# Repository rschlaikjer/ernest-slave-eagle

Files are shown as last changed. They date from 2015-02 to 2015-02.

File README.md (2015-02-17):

# Ernest Slave Node Schematics
Eagle files for data collection nodes

[Master Project Repo](https://github.com/rschlaikjer/Ernest)

## What is this
Ernest is the next step of the [ArNest](https://github.com/rschlaikjer/ArNest),
and takes it from a single-location thermostat to a many node system consisting
of a base station and one or more smaller nodes that collect and report
atmospheric data to the base. This way the system can monitor multiple rooms, as
well as the outside conditions.

These EAGLE files show the schematic for hooking up the slave nodes, as well as
a board layout for printing your own slave boards.

For the code to run on the slave nodes,
[see here](https://github.com/rschlaikjer/ernest-slave-code).

## Parts list
(All prices per unit and approximate)

- ($2.00) Atmega 328P (with arduino-style bootloader)
- ($3.19) USB FTDI programmer
- ($1.50) BMP180 breakout board
- ($13.75) (Optional) HIH-6130 humidity sensor
- ($0.98) nrf24L01 wireless transciever
- ($0.39) LM1117 3.3V regulator
- ($0.07) 16 MHz crystal oscillator
- ($0.03) 22pF capacitors
- ($0.08) Momentary reset switch
- ($0.32) 4-pin DIP switch
- ($0.01) 320 Ohm resistors
- ($0.03) LEDs
- ($0.30) 2.5mm barrel jack (for power)

**Total BOM: Approx. $5.86 per board** + 13.75 for humidity, as well as the cost
of PCB manufacture.

## Pretty Pictures

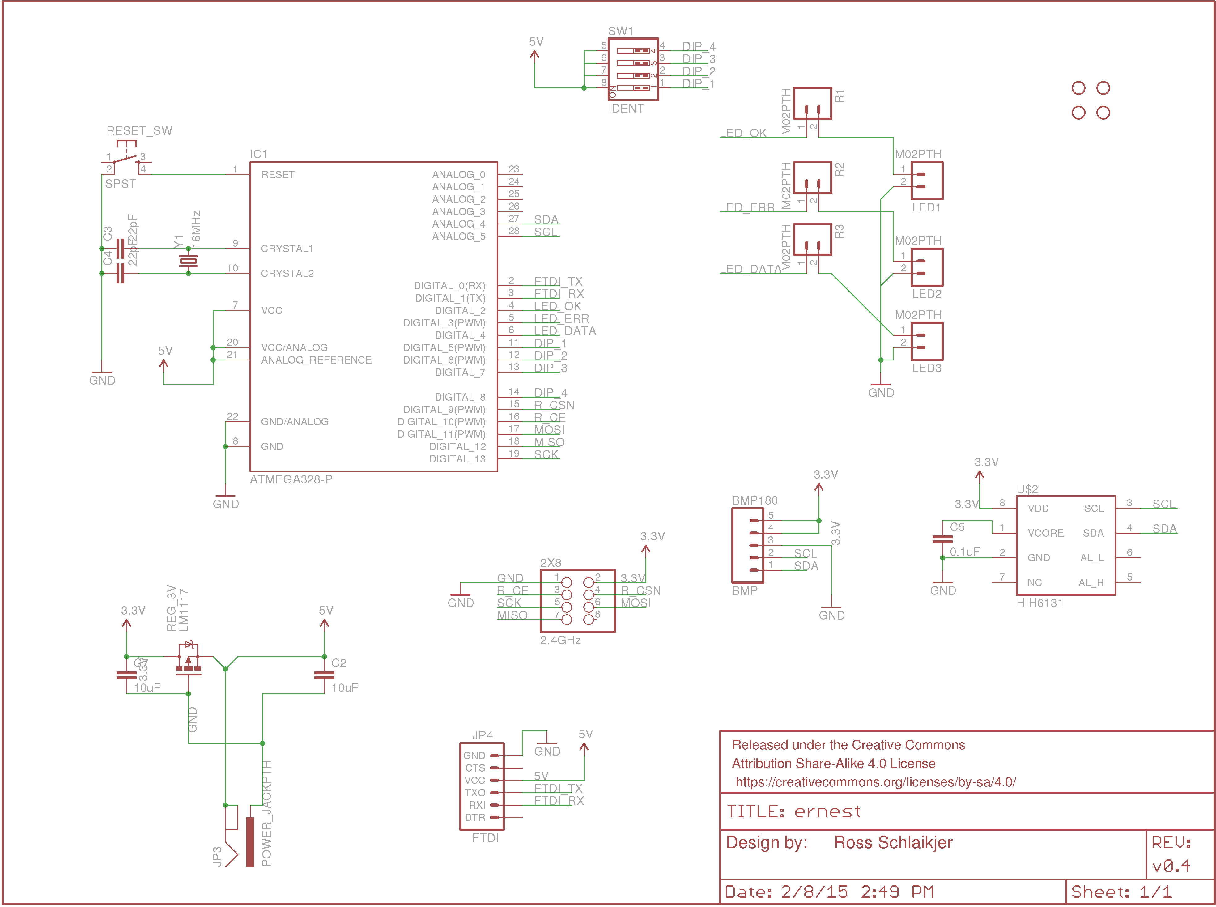
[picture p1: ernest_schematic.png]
Schematic


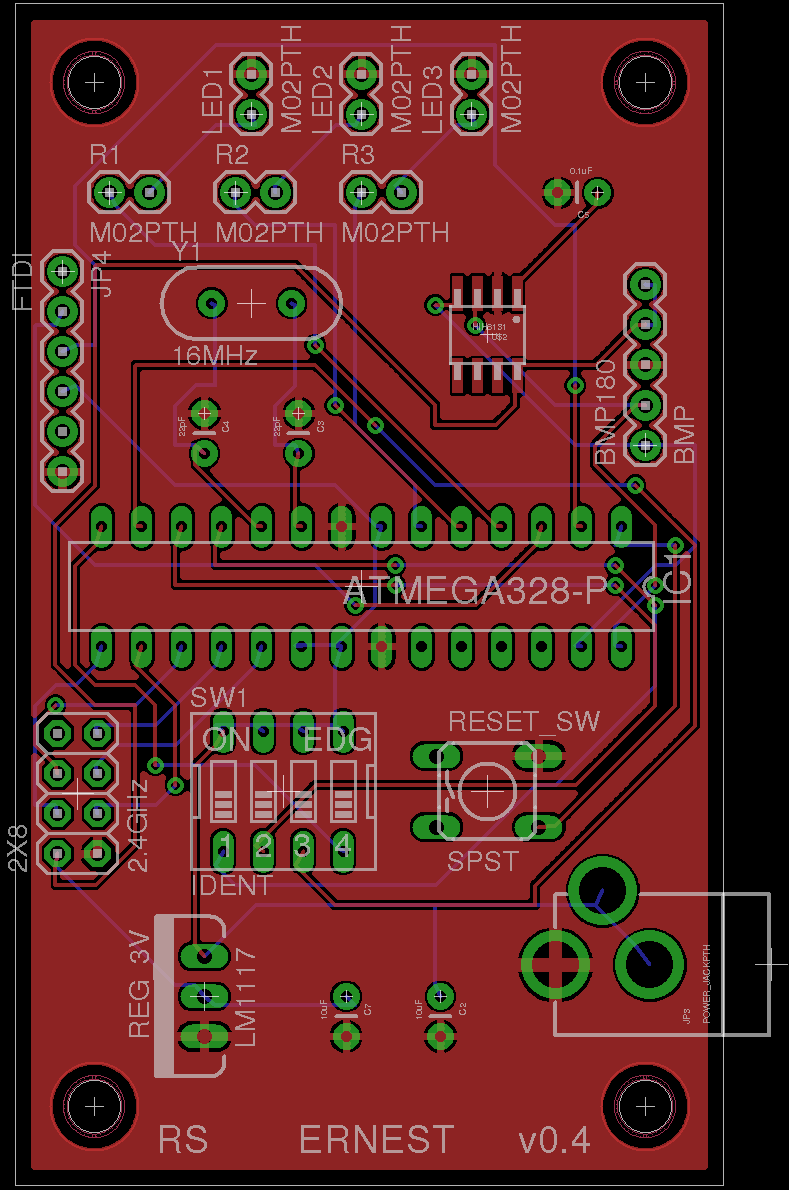
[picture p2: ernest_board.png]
Board Layout


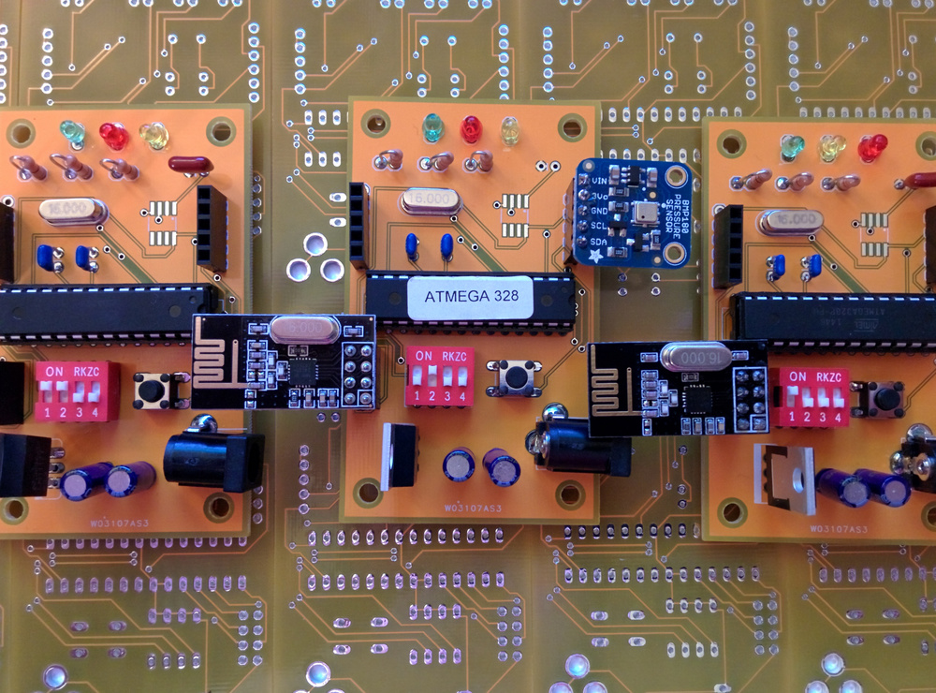
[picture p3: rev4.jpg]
Current Prototype Current prototype


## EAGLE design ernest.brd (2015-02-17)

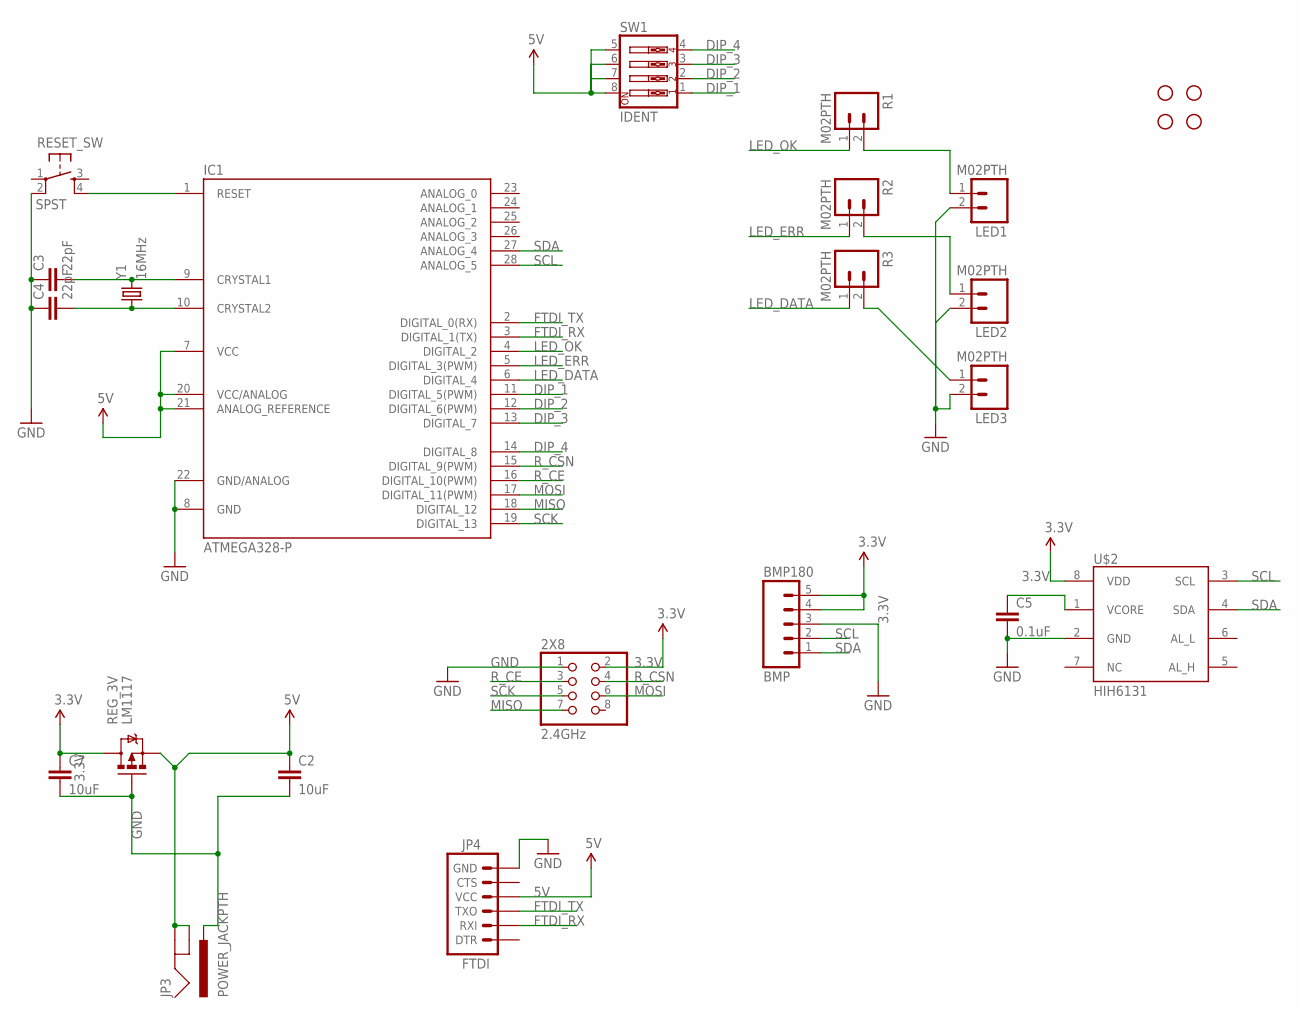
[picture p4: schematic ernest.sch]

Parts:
2X8: 2.4GHz; 2X04
BMP180: BMP; 1X05
C2, C7: 10uF; CAP-PTH-SMALL
C3, C4: 22pF; CAP-PTH-SMALL
C5: 0.1uF; CAP-PTH-SMALL
IC1: ATMEGA328-P; DIL28-3
JP3: POWER_JACKPTH; POWER_JACK_PTH
JP4: FTDI; 1X06
LED1, LED2, LED3: M02PTH; 1X02
R1, R2, R3: M02PTH; 1X02
REG_3V: LM1117; TO220V
RESET_SW: SPST; TAC-SWITCH-PTH
STANDOFF1, STANDOFF2, STANDOFF3, STANDOFF4: STAND-OFF
SW1: IDENT; EDG-04
U$2: HIH6131; SOIC8
Y1: 16MHz; HC49US

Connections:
3.3V: 2X8.2, BMP180.4, BMP180.5, C7.1, REG_3V.2 (D), U$2.8 (VDD)
5V: C2.1, IC1.7 (VCC), IC1.20 (VCC/ANALOG), IC1.21 (ANALOG_REFERENCE), JP3.GND, JP3.GNDBREAK, JP4.4 (VCC), REG_3V.3 (S), SW1.5, SW1.6, SW1.7, SW1.8
DIP_1: IC1.11 (DIGITAL_5(PWM)), SW1.1
DIP_2: IC1.12 (DIGITAL_6(PWM)), SW1.2
DIP_3: IC1.13 (DIGITAL_7), SW1.3
DIP_4: IC1.14 (DIGITAL_8), SW1.4
FTDI_RX: IC1.3 (DIGITAL_1(TX)), JP4.2 (RXI)
FTDI_TX: IC1.2 (DIGITAL_0(RX)), JP4.3 (TXO)
GND: 2X8.1, BMP180.3, C2.2, C3.1, C4.1, C5.2, C7.2, IC1.8 (GND), IC1.22 (GND/ANALOG), JP3.PWR, JP4.6 (GND), LED1.2, LED2.2, LED3.2, REG_3V.1 (G), RESET_SW.2, U$2.2 (GND)
LED_DATA: IC1.6 (DIGITAL_4), R3.1
LED_ERR: IC1.5 (DIGITAL_3(PWM)), R2.1
LED_OK: IC1.4 (DIGITAL_2), R1.1
MISO: 2X8.7, IC1.18 (DIGITAL_12)
MOSI: 2X8.6, IC1.17 (DIGITAL_11(PWM))
unnamed: LED1.1, R1.2
unnamed: LED2.1, R2.2
unnamed: LED3.1, R3.2
unnamed: IC1.1 (RESET), RESET_SW.4
unnamed: C5.1, U$2.1 (VCORE)
unnamed: C3.2, IC1.9 (CRYSTAL1), Y1.2
unnamed: C4.2, IC1.10 (CRYSTAL2), Y1.1
R_CE: 2X8.3, IC1.16 (DIGITAL_10(PWM))
R_CSN: 2X8.4, IC1.15 (DIGITAL_9(PWM))
SCK: 2X8.5, IC1.19 (DIGITAL_13)
SCL: BMP180.2, IC1.28 (ANALOG_5), U$2.3 (SCL)
SDA: BMP180.1, IC1.27 (ANALOG_4), U$2.4 (SDA)

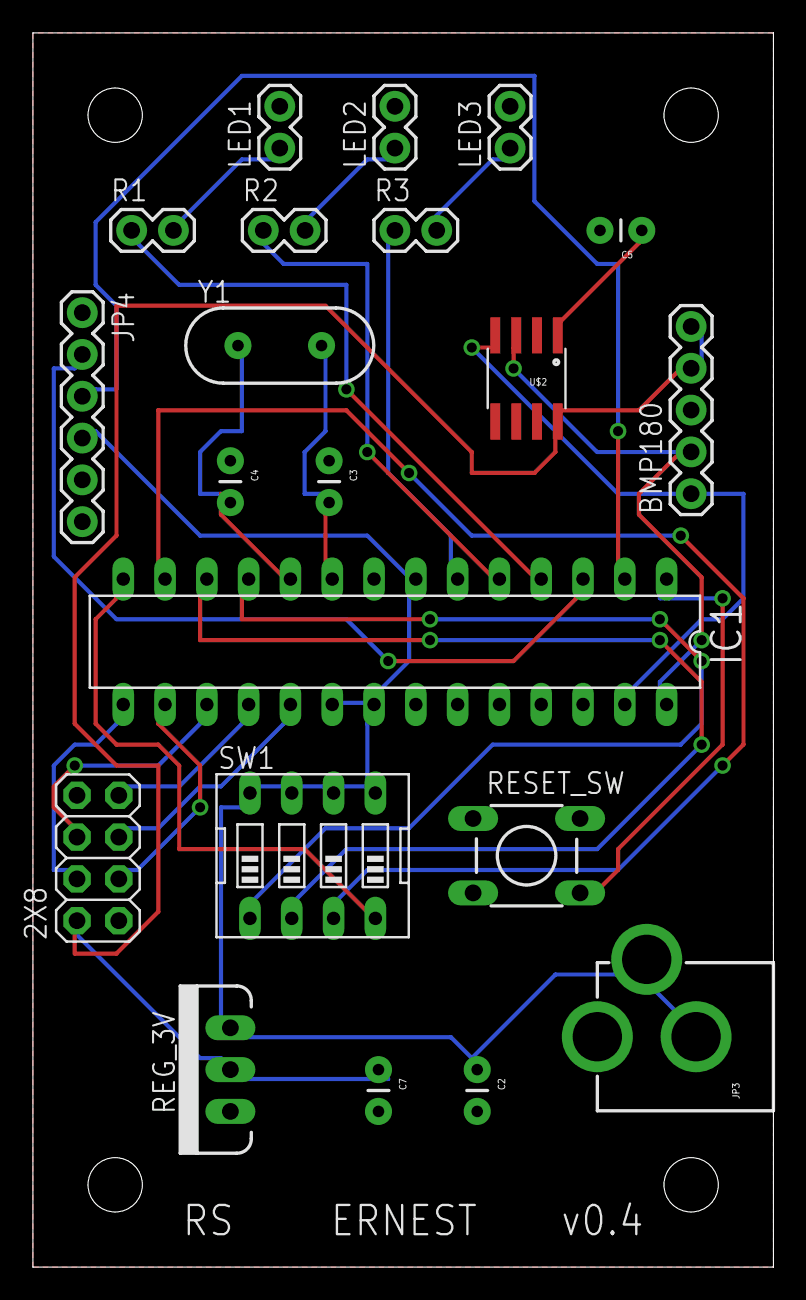
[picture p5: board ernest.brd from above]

Board: 2 copper layers, 45.0 x 75.0 mm, 25 parts (0 on the bottom side), 26 nets.

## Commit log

2015-01-20 ERNEST v0.1
    Mounting for:
    - Arduino Micro
    - BMP180
    - 2.4GHz transciever
    - 3 status LEDs
    - 3 resistors for LEDs
    [schema.brd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]
2015-01-20 ERNEST v0.2
    Added a DIP switch for quick setting of the node ID, to avoid
    having to reflash the thing each time.
    [schema.brd, schema.sch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]
2015-01-20 Add mounting holes
    [schema.brd, schema.sch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]
2015-01-31 Revision 4
    Move away from using an actual Arduino micro to a raw ATMEGA chip to save on
    cost. Also adds in a humidity sensor (Honeywell 6131) to the list of sensors.
    [ernest.brd, ernest.sch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]
2015-01-31 Remove unnecessary 5v reg
    [ernest.brd, ernest.sch]
2015-02-08 Reorder SPI pins based off breadboard test
    [ernest.brd, ernest.sch]
2015-02-08 Add rough BOM
2015-02-17 V0.4 release
    [ernest.brd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]

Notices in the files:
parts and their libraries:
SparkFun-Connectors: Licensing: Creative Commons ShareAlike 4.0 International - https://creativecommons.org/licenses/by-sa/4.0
